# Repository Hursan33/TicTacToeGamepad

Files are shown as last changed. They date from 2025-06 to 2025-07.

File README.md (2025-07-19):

# TicTacToeGamepad

## TBD 
Test new version of code, assemble the integrated arduino version, upload edited case

## 1 Introduction
This project is an implementation of a Tic Tac Toe game using both hardware and software. The
purpose of the project was to practice working with an 8-bit mcu on register level, but I worked on it more and created a standalone version.
## 2 Materials and technologies
* MCU (I used Avr curiosity nano for school and an Arduino pro micro for standalone)  
* 9x Keyboard switches  
* 9x SK6812MINI-E LEDs  
* 3x 100uF capacitors  
* 1x 330r resistor  
  
The game itself is played on a 3x3 playing field made from keyboard switches, which are soldered onto
a PCB I designed. The PCB sits in a 3D printed case.

## 2 Functions
The game uses addressable LEDs to show the board state. Each player has their own color, which is
shown on the fields the player has occupied. After the game is over, whether it was a draw or a player
won, there is an animation and 5 second delay, after which the game restarts. The first player to act
is decided by which player won the last game, or which player went last. There are 2 possible game
modes:  

* Classic  
* 3-mark rule  

Both game modes can be played in single player, which replaces the second player with a bot.
### 2.1 Classic
This game mode uses the classic rules of a 3x3 tic tac toe game. The player wins by putting 3 marks
in a row, column or diagonal. After the board is filled and no player has won, the game is declared as
a draw.
1
### 2.2 3-mark rule
Here each player only gets 3 marks. After that they must move their oldest mark to a new position.
In this game mode there is no draw, a player must win to end the game. The moving mark is shown
by being dimmer than the rest.
### 2.3 Bot
The bot uses a simple algorithm to decide which space it wants to occupy.
1. Checks if a win is possible, then it places the mark there.  
2. Checks if the player can win, then it blocks the player.  
3. If the center is free, it puts the mark there.  
4. Checks every corner in a random order and occupies it if possible.  
5. Checks every side field in a random order and occupies it if possible.

In the 3-mark rule, when checking if the player can win, it also remembers which mark the player is
moving. This ensures that the bot blocks the correct field.
### 3.4 Ending animation
After the game ends, either by a player winning or a draw, there is an animation played. The animation
lights up the LEDs in a “2” shape with the color of the winning player, or in the case of a draw with
the “draw” color.
## 3 Costumizations
There are a few customizations in the game. First, the game mode and if the bot is active can be
set. The colors of each player and draw are also customizable, using RGB format. The dimness of the
moving mark is also possible to change.
To change these settings these macros can be modified in the “config.h” file:

* GAME_MODE – 1 (3-mark rule) or 0 (Classic).  
* BOT – 1 (Bot is turned on) or 0 (Bot is off).  
* PLAYER_N_COLOR and DRAW_COLOR – has this syntax (Color) R, G, B, you replace the R, G, B
with the corresponding colors of the value. Player colors and draw color all have to be different
otherwise an error occurs.  
* DIM_DIV – the amount by which the values of the color are divided, e.g. DIM_DIV 16 makes the
LEDs be 1
16 of their brightness.  

If there were changes to any of the settings the game can be simply re-flashed onto the mcu by using
the Makefile in the project folder.
### 3.1 Error
If an error occurs, the board starts blinking red. In case this happens check your color values, because
some of them have the same values.
## Schematic and PCB


The gerber files for the PCB are present in the repository.
## PINOUT


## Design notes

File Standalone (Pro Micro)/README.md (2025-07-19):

# Standalone arduino pro micro version
This is a reworked version of the TicTacToe gamepad. It is has a battery and no need to be plugged into a computer.
## 1 Software
Sadly, I was unable to get the timing right for the LEDs. In the end, I decided to use Arduino code (instead of bare metal) and used the Neopixel library to control the LEDs.
## 2 Components
This variant of the projects uses additional components. 
* 3 x sliding switches like [this](https://www.aliexpress.com/item/1005005877582064.html?spm=a2g0o.order_list.order_list_main.116.5a0a1802KlUbMT) one
* 1 x charging circuit like [this](https://www.aliexpress.com/item/1005006734963929.html?spm=a2g0o.order_list.order_list_main.22.2a7718028qB14W)
* 1 x small lithium battery, I used a 180mAh battery because it was small and I had it already on hand, but a bigger battery wouldn't hurt.
## 3 Images and building
a3
a2
a1
2 of the 3 switches are connected to pins A0 and A2, the position of these switches at startup controls whether the Bot or 3-mark rule functionalities are turned on, thus there is no need to edit the code. The last switch is the power switch and completes the circuit between the MCU and the charging circuit. I repurposed an old micro usb connecter between the MCU and charging circuit but you can hardwire it.
The pin connections can be found in the code [here](https://github.com/Hursan33/TicTacToeGamepad/blob/main/Standalone%20(Pro%20Micro)/firmware.ino).

a4
a5
a6

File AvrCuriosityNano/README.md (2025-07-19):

# Avr Curiosity Nano version
This version of the software is written in C, compiled using avrgcc and flashed with avrdude. I wrote the driver for
the LEDs, which are sensitive to timing, so I decided to use `nop` instructions. They are used to create delay, which is more accurate than using delay functions from
`<util/delay.h>`. For the number of cycles, I used the LED datasheet as a reference. 
## Status
This version of the project was an assignment on a school course and will *NOT* be updated anymore.
## Connection
In this version the MCU was connected via the 9 pins present on the PCB, 
but it can be made completely stand-alone.
## Images



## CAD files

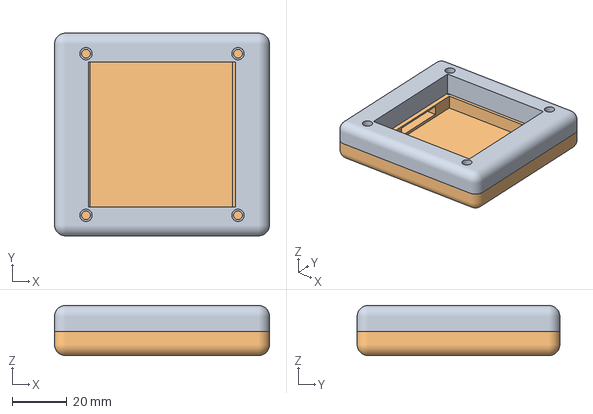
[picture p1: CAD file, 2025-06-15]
AvrCuriosityNano/game_pad_case.3mf
78.5 x 74.0 x 18.3 mm
TopCase

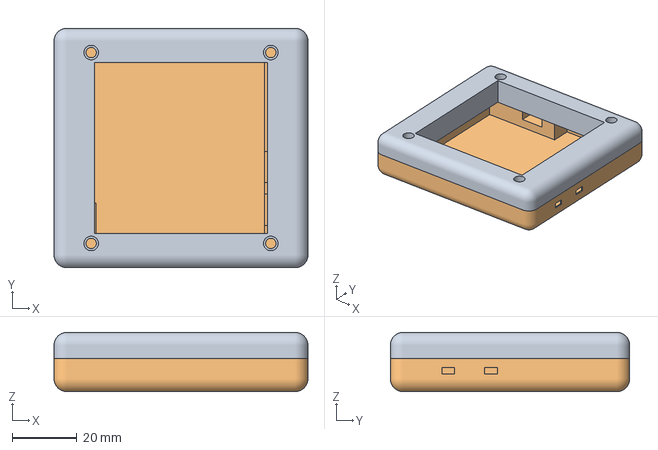
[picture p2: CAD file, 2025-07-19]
Standalone (Pro Micro)/Case.3mf
78.5 x 74.0 x 18.3 mm
TopCase

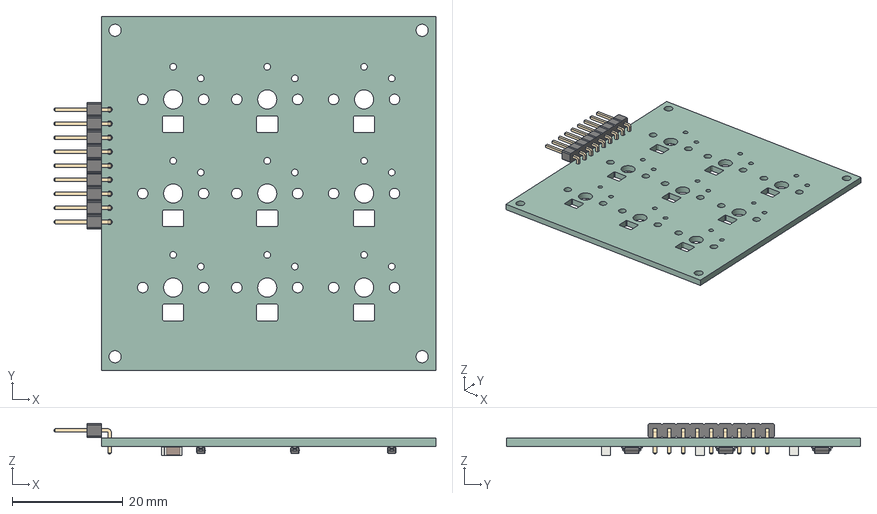
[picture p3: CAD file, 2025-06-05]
TicTacToe-KiCad/TicTacToe - pb171.step
69.0 x 64.0 x 5.82 mm
PinHeader_1x09_P2.54mm_Horizontal
D_SOD-123 x 9
C_1206_3216Metric x 3
TicTacToe - pb171_PCB

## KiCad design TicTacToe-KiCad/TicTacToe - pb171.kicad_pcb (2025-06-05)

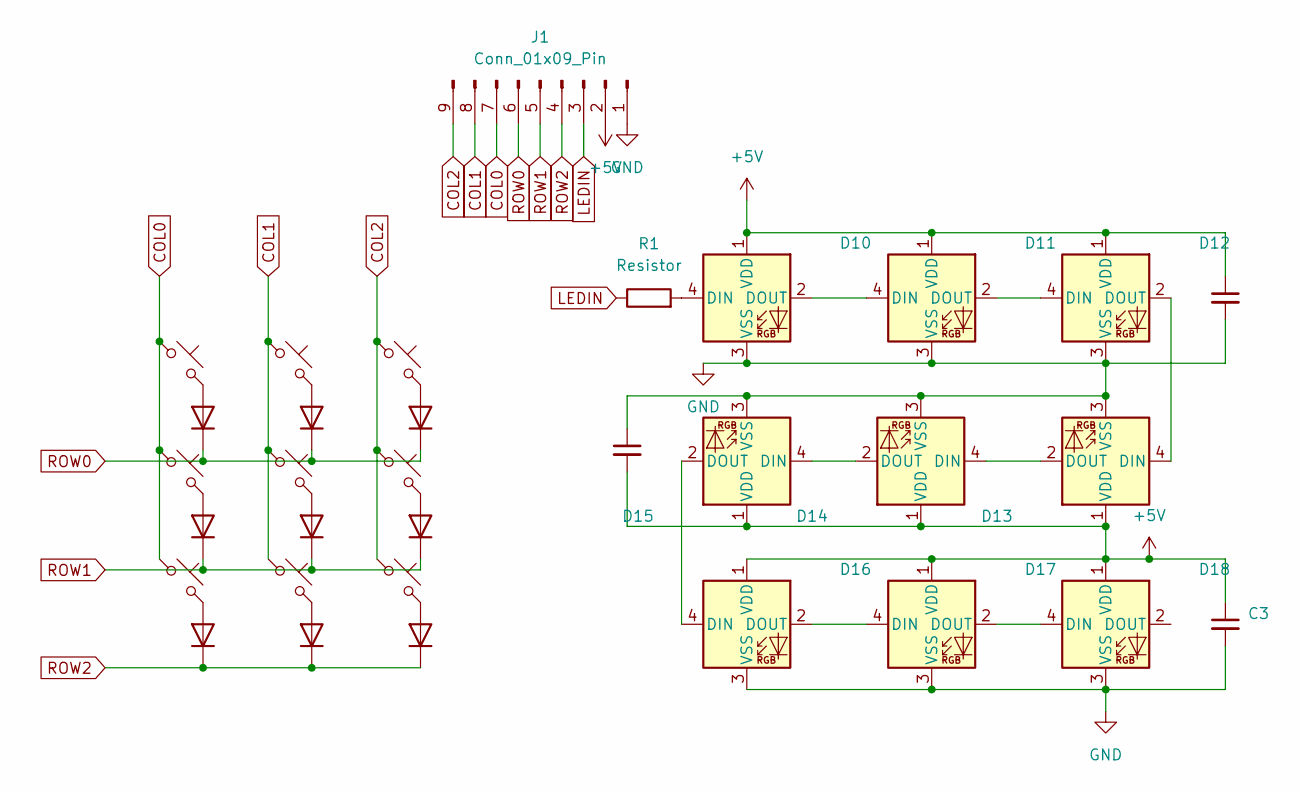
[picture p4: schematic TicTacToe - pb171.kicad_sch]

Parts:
C1, C2, C3: C_Small; C_1206_3216Metric
D1, D2, D3, D4, D5, D6, D7, D8, D9: D; D_SOD-123
D10, D11, D12, D13, D14, D15, D16, D17, D18: LED_WS2812B; SK6812-MINI-E
J1: Conn_01x09_Pin; PinHeader_1x09_P2.54mm_Horizontal
R1: Resistor; Resistor_1206
S1, S2, S3, S4, S5, S6, S7, S8, S9: Keyswitch; Choc_V1_1.00u

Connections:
+5V: C1.1, C2.2, C3.1, D10.1 (VDD), D11.1 (VDD), D12.1 (VDD), D13.1 (VDD), D14.1 (VDD), D15.1 (VDD), D16.1 (VDD), D17.1 (VDD), D18.1 (VDD), J1.2
COL0: J1.7, S1.1, S4.1, S7.1
COL1: J1.8, S2.1, S5.1, S8.1
COL2: J1.9, S3.1, S6.1, S9.1
GND: C1.2, C2.1, C3.2, D10.3 (VSS), D11.3 (VSS), D12.3 (VSS), D13.3 (VSS), D14.3 (VSS), D15.3 (VSS), D16.3 (VSS), D17.3 (VSS), D18.3 (VSS), J1.1
LEDIN: J1.3, R1.1
unnamed: D1.2 (A), S1.2
unnamed: D2.2 (A), S2.2
unnamed: D3.2 (A), S3.2
unnamed: D4.2 (A), S4.2
unnamed: D5.2 (A), S5.2
unnamed: D6.2 (A), S6.2
unnamed: D7.2 (A), S7.2
unnamed: D8.2 (A), S8.2
unnamed: D9.2 (A), S9.2
unnamed: D10.4 (DIN), R1.2
unnamed: D10.2 (DOUT), D11.4 (DIN)
unnamed: D11.2 (DOUT), D12.4 (DIN)
unnamed: D12.2 (DOUT), D13.4 (DIN)
unnamed: D13.2 (DOUT), D14.4 (DIN)
unnamed: D14.2 (DOUT), D15.4 (DIN)
unnamed: D15.2 (DOUT), D16.4 (DIN)
unnamed: D16.2 (DOUT), D17.4 (DIN)
unnamed: D17.2 (DOUT), D18.4 (DIN)
ROW0: D1.1 (K), D2.1 (K), D3.1 (K), J1.6
ROW1: D4.1 (K), D5.1 (K), D6.1 (K), J1.5
ROW2: D7.1 (K), D8.1 (K), D9.1 (K), J1.4

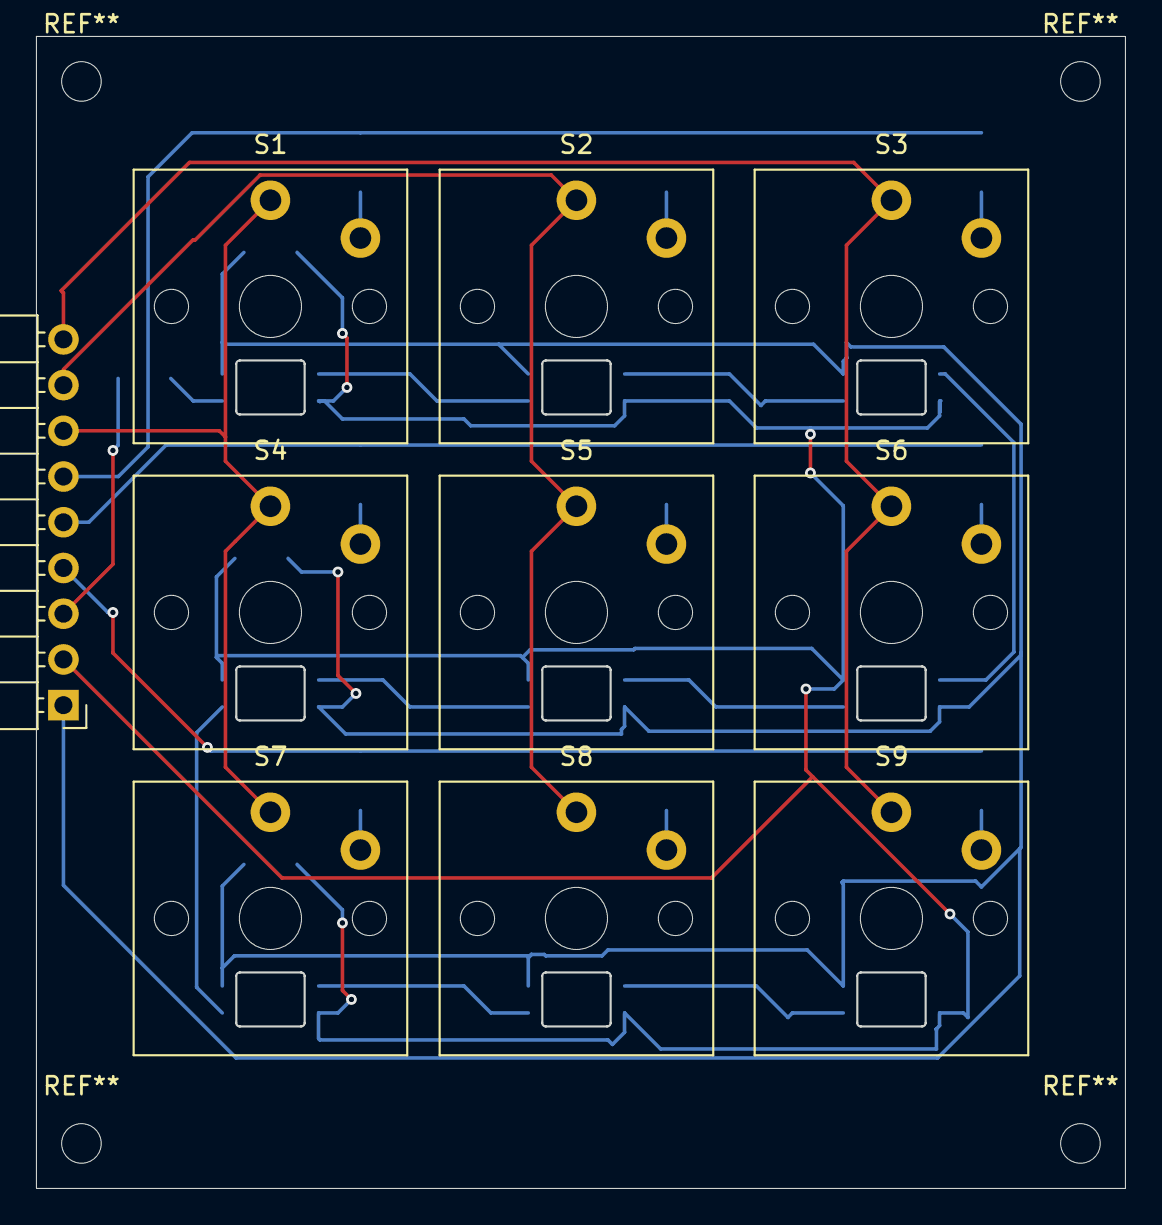
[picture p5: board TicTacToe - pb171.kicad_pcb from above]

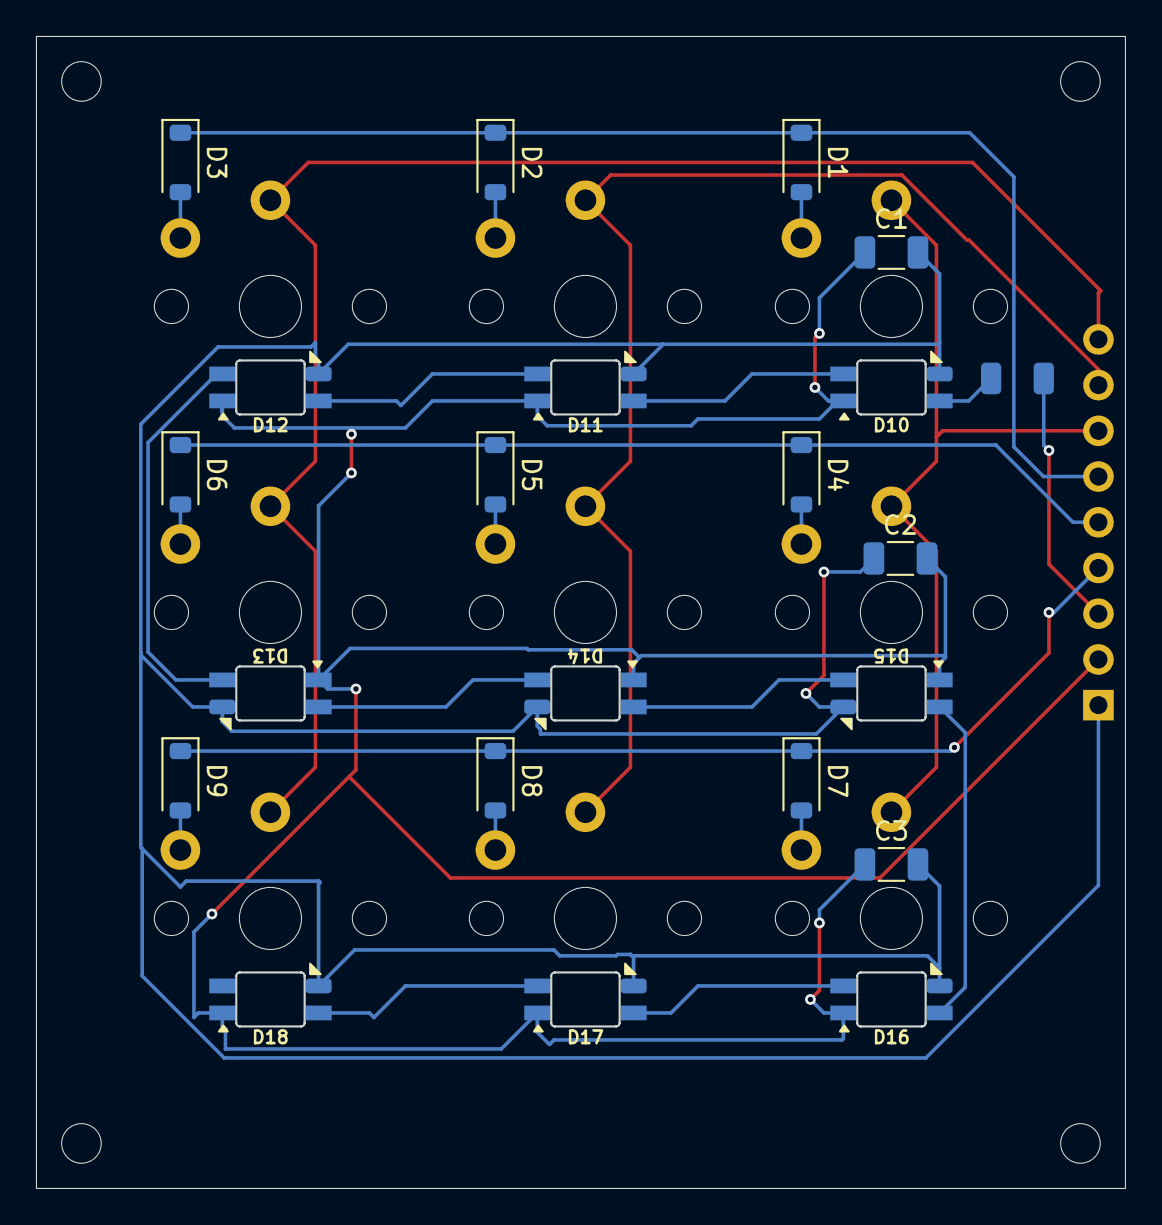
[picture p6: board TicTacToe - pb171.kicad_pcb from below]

Board: 2 copper layers, 60.5 x 64.0 mm, 32 parts (22 on the bottom side), 27 nets.

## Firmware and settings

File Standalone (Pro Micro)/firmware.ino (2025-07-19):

#include <Adafruit_NeoPixel.h> // Include the NeoPixel library

#define LED_PIN    4    // Digital pin connected to the NeoPixel data input
#define NUM_LEDS   9    // Number of NeoPixels in your 3x3 grid
#define ANIM_SPEED 200

Adafruit_NeoPixel pixels(NUM_LEDS, LED_PIN, NEO_GRB + NEO_KHZ800);

uint8_t GAME_MODE;
uint8_t BOT;
uint8_t PLAYER_1_COLOR[3] = {255, 0, 247};
uint8_t PLAYER_2_COLOR[3] = {0, 255, 8};
uint8_t DRAW_COLOR[3] = {255, 0, 0};
#define DIM_DIV 16 //Sets the brightness of the dim space (only GAMEMODE 1),
                   //Decides by what number will the values of color be dived by

const int rowPins[] = {8, 7, 6}; // Row 0 (top) -> A3, Row 1 (middle) -> A2, Row 2 (bottom) -> A1

const int colPins[] = {14, 16, 10}; // Col 0 (left) -> Pin 15, Col 1 (middle) -> Pin 16, Col 2 (right) -> Pin 14

int keypadToNeoPixelIndex[3][3] = {
  {0, 1, 2}, // If Key '1' -> LED 0, '2' -> LED 1, '3' -> LED 2
  {5, 4, 3}, // If Key '4' -> LED 3, '5' -> LED 4, '6' -> LED 5
  {6, 7, 8}  // If Key '7' -> LED 6, '8' -> LED 7, '9' -> LED 8
};

uint8_t board[3][3] = {{0}};
    
uint8_t player1_moves[3][2] = {{255}};
uint8_t player2_moves[3][2] = {{255}};
uint8_t p1_count = 0;
uint8_t p2_count = 0;

uint8_t turnCounter = 0;
uint8_t row = 0;
uint8_t col = 0;
uint8_t player;
uint8_t banned_c = -1;
uint8_t banned_r = -1;


void setup() {
  pinMode(A2, INPUT_PULLUP);
  pinMode(A0, INPUT_PULLUP);
  
  
  GAME_MODE = digitalRead(A0) == LOW;  //OR put 0, for traditional tic-tac-toe
  BOT = digitalRead(A2) == LOW;
  
  Serial.begin(9600);
  
  // Initialize NeoPixel strip
  pixels.begin();         // Initialize the NeoPixel library
  pixels.clear();         // Turn off all NeoPixels initially
  pixels.show();          // Send the updated pixel colors to the hardware.

  // Set row pins as outputs and ensure they are all LOW initially (inactive)
  for (int i = 0; i < 3; i++) {
    pinMode(rowPins[i], OUTPUT);
    digitalWrite(rowPins[i], HIGH); // All rows are inactive (LOW) by default
  }

  // Set column pins as inputs and enable internal pull-up resistors
  for (int i = 0; i < 3; i++) {
    pinMode(colPins[i], INPUT_PULLUP);
  }
}

void loop() {
  Serial.println("BOT AND GAMEMODE");
  Serial.print(BOT);
  Serial.print(" ");
  Serial.println(GAME_MODE);
  printBoard(board);
  player = turnCounter % 2 == 0 ? 1 : 2;
  uint8_t (*moves)[2] = player == 1 ? player1_moves : player2_moves;
  uint8_t *move_count = player == 1 ? &p1_count : &p2_count;
  uint8_t *color = player == 1 ? PLAYER_1_COLOR : PLAYER_2_COLOR;

  if (GAME_MODE) {
      if (*move_count == 3) {
          pixels.setPixelColor(keypadToNeoPixelIndex[moves[0][0]][moves[0][1]], pixels.Color(color[0] / DIM_DIV, color[1] / DIM_DIV, color[2] / DIM_DIV));
          pixels.show();
      }
  }
  
  
  while (!scanKey(&row, &col)) {}
  if (board[row][col] != 0) {
      return;
  }

  if (GAME_MODE) {
      remove_old(board, moves, move_count);
      moves[*move_count - 1][0] = row;
      moves[*move_count - 1][1] = col;
  }
  
  board[row][col] = player;
  pixels.setPixelColor(keypadToNeoPixelIndex[row][col], pixels.Color(color[0], color[1], color[2]));
  pixels.show();
  
  check_end(board, player, &p1_count, &p2_count, &banned_c, &banned_r);
  
  turnCounter++;

  if (!BOT) {
      return;
  }

  delay(500);
  player = 2;
  color = PLAYER_2_COLOR;
  moves = player2_moves;
  move_count = &p2_count;

  int bot_c, bot_r;
  if (GAME_MODE) {
      if (*move_count == 3) {
          banned_c = moves[0][1];
          banned_r = moves[0][0];

          pixels.setPixelColor(keypadToNeoPixelIndex[moves[0][0]][moves[0][1]], pixels.Color(color[0] / DIM_DIV, color[1] / DIM_DIV, color[2] / DIM_DIV));
          pixels.show();
          _delay_ms(1000);
      }
      remove_old(board, moves, move_count);
  }

  bot_move(board, &bot_r, &bot_c, banned_r, banned_c, p1_count, player1_moves[0]);
  Serial.print("Bot moved to ");
  Serial.print(bot_r);
  Serial.print(" ");
  Serial.println(bot_c);
  if (GAME_MODE) {
      moves[*move_count - 1][0] = bot_r;
      moves[*move_count - 1][1] = bot_c;
  }

  pixels.setPixelColor(keypadToNeoPixelIndex[bot_r][bot_c], pixels.Color(color[0], color[1], color[2]));
  pixels.show();

  check_end(board, player, &p1_count, &p2_count, &banned_c, &banned_r);

  turnCounter++;
}

bool prev_states[3][3] = {{true}};

bool gameEnded(uint8_t board[3][3], int currPlayer, bool botCheck) {
    for (int i = 0; i < 3; i++) {
        if (board[i][0] == board[i][1] && board[i][1] == board[i][2] && board[i][0] == currPlayer){
            int winners[3][2] = {{i, 0}, {i, 1}, {i, 2}};
            if (!botCheck) {
              blinkWinner(winners, currPlayer == 1 ? PLAYER_1_COLOR : PLAYER_2_COLOR);
            }
            return true;
        }
    }
    
    for (int i = 0; i < 3; i++) {
        if (board[0][i] == board[1][i] && board[1][i] == board[2][i] && board[0][i] == currPlayer){
            int winners[3][2] = {{0, i}, {1, i}, {2, i}};
            if (!botCheck) {
              blinkWinner(winners, currPlayer == 1 ? PLAYER_1_COLOR : PLAYER_2_COLOR);
            }
            return true;
        }
    }
    
    if (board[0][0] == board[1][1] && board[1][1] == board[2][2] && board[0][0] == currPlayer) {
        int winners[3][2] = {{0, 0}, {1, 1}, {2, 2}};
        if (!botCheck) {
          blinkWinner(winners, currPlayer == 1 ? PLAYER_1_COLOR : PLAYER_2_COLOR);
        }
        return true;
    }
    
    if (board[2][0] == board[1][1] && board[1][1] == board[0][2] && board[2][0] == currPlayer) {
        int winners[3][2] = {{2, 0}, {1, 1}, {0, 2}};
        if (!botCheck) {
          blinkWinner(winners, currPlayer == 1 ? PLAYER_1_COLOR : PLAYER_2_COLOR);
        }
        return true;
    }
    
    return false;
}

bool scanKey(uint8_t* row, uint8_t* col) {
    bool keyPressed = false;
    for (int r = 0; r < 3; r++) {
        digitalWrite(rowPins[r], LOW);
        _delay_ms(5);

        for(int c = 0; c < 3; c++) {
            bool pressed = !(digitalRead(colPins[c]));
                
            if (pressed && !prev_states[r][c]) {
                *col = c;
                *row = r;
                Serial.print("found ");
                Serial.print(c);
                Serial.print(" ");
                Serial.println(r);
                keyPressed = true;
            }
            
            prev_states[r][c] = pressed;
        }

        digitalWrite(rowPins[r], HIGH);
        _delay_ms(20);
    }
    
    return keyPressed;
}

bool drawCheck(uint8_t board[3][3]) {
    for (int i = 0; i < 3; i++) {
        for (int j = 0; j < 3; j++) {
            if (board[i][j] == 0) {
                return false;
            }
        }
    }
    
    return true;
}

void remove_old(uint8_t board[3][3], uint8_t moves[3][2], uint8_t *move_count) {
    if (*move_count == 3) {
        uint8_t *move = moves[0];

        board[move[0]][move[1]] = 0;

        uint8_t led = move[0] * 3 + move[1];
        if (move[0] == 1) {
            led = 3 + (2 - move[1]);
        }
        pixels.setPixelColor(keypadToNeoPixelIndex[move[0]][move[1]], pixels.Color(0, 0, 0));

        for (int i = 0; i < 2; i++) {
            moves[i][0] = moves[i + 1][0];
            moves[i][1] = moves[i + 1][1];
        }
    } else {
        (*move_count)++;
    }

    
}

bool is_empty(uint8_t board[3][3], int row, int col) {
    return board[row][col] == 0;
}

void randomize(int indices[4]) {
    for (int i = 3; i >= 0; --i){
        //generate a random number [0, n-1]
        int j = rand() % 4;

        //swap the last element with element at random index
        int temp = indices[i];
        indices[i] = indices[j];
        indices[j] = temp;
    }
}

void bot_move(uint8_t board[3][3], int *row, int *col, int b_r, int b_c, int moves_count, uint8_t move[2]) {
    for (int i = 0; i < 3; i++) {
        for (int j = 0; j < 3; j++) {
            if (b_c != -1 && b_r == i && b_c == j) {
                continue;
            }
            if (is_empty(board, i, j)) {

                board[i][j] = 2;
                if (gameEnded(board, 2, true)) {
                    //ZAPISE A VYHRA
                    *col = j;
                    *row = i;
                    return;
                }
                board[i][j] = 0;

            }
        }
    }

    for (int i = 0; i < 3; i++) {
        for (int j = 0; j < 3; j++) {
            if (b_c != -1 && b_r == i && b_c == j) {
                continue;
            }
            if (is_empty(board, i, j)) {
                board[i][j] = 1;
                if (moves_count == 3) {
                    board[move[0]][move[1]] = 0;
                }
                if (gameEnded(board, 1, true)) {
                    //ZAPISE A BLOKUJE
                    board[i][j] = 2;
                    *col = j;
                    *row = i;
                    return;
                }
                board[i][j] = 0;
                if (moves_count == 3) {
                    board[move[0]][move[1]] = 1;
                }
            }
        }
    }

    if (!(b_c != -1 && b_c == 1 && b_r == 1) && is_empty(board, 1, 1)) {
        *col = 1;
        *row = 1;
        board[1][1] = 2;
        return;
    }

    int indices[4] = {0, 1, 2, 3};
    randomize(indices);

    int corners[4][2] = { {0,0}, {0,2}, {2,0}, {2,2} };
    for (int i = 0; i < 4; i++) {
        int c = corners[indices[i]][1];
        int r = corners[indices[i]][0];
        if (b_c != -1 && b_c == c && b_r == r) {
            continue;
        }
        if (is_empty(board, r, c)) {
            Serial.print(c);
            Serial.println(r);
            board[r][c] = 2;
            *col = c;
            *row = r;
            return;
        }
    }

    randomize(indices);

    int sides[4][2] = { {0,1}, {1,0}, {2,1}, {1,2} };
    for (int i = 0; i < 4; i++) {
        int c = sides[indices[i]][1];
        int r = sides[indices[i]][0];
        if (b_c != -1 && b_c == c && b_r == r) {
            continue;
        }
        if (is_empty(board, r, c)) {
            board[r][c] = 2;
            *col = c;
            *row = r;
            return;
        }
    }
}

void check_end(uint8_t board[3][3], int player, uint8_t *p1_count, 
    uint8_t *p2_count, uint8_t *banned_c, uint8_t *banned_r) {
    bool game_ended = gameEnded(board, player, false);
    if (game_ended || drawCheck(board)) {
        ending_animation(game_ended ? (player == 1 ? PLAYER_1_COLOR : PLAYER_2_COLOR) : DRAW_COLOR);
        
        for (int i = 0; i < 3; i++) {
            for (int j = 0; j < 3; j++) {
                board[i][j] = 0;
            }
        }
        
        *p1_count = 0;
        *p2_count = 0;
        *banned_c = -1;
        *banned_r = -1;
    }
}

void ending_animation(uint8_t* rgb) {

    delay(700);
    pixels.clear();
    pixels.show();
    delay(ANIM_SPEED);
    for (int i = 0; i < 9; i++) {
        pixels.setPixelColor(i, pixels.Color(rgb[0], rgb[1], rgb[2]));
        pixels.show();
        delay(ANIM_SPEED);
    }

    for (int i = 0; i < 3; i++) {
        delay(400);
        pixels.clear();
        pixels.show();
        delay(400);
        for (int j = 0; j < 9; j++) {
            pixels.setPixelColor(j, pixels.Color(rgb[0], rgb[1], rgb[2]));
        }
        pixels.show();
    }

    delay(2500);
    pixels.clear();
    pixels.show();
}

void blinkWinner(int winners[3][2], uint8_t* rgb) {
  for (int j = 0; j < 3; j++) { 
    delay(ANIM_SPEED * 2);
    for (int i = 0; i < 3; i++) {
      int index = keypadToNeoPixelIndex[winners[i][0]][winners[i][1]];
      Serial.print(winners[i][0]);
      Serial.println(winners[i][1]);
      pixels.setPixelColor(index, pixels.Color(0,0,0));
    }
    pixels.show();
    delay(ANIM_SPEED * 2);
    for (int i = 0; i < 3; i++) {
      int index = keypadToNeoPixelIndex[winners[i][0]][winners[i][1]];
      pixels.setPixelColor(index, pixels.Color(rgb[0],rgb[1],rgb[2]));
    }
    pixels.show();
  }
}

//
//bool check_color(Color color1, Color color2) {
//    return color1.rgb[0] == color2.rgb[0] &&
//            color1.rgb[1] == color2.rgb[1] &&
//            color1.rgb[2] == color2.rgb[2];
//}

void error_anim() {
    while (1) {
        for (int j = 0; j < 9; j++) {
            pixels.setPixelColor(j, pixels.Color(255, 0, 0));
        }
        pixels.show();
        delay(400);
        pixels.clear();
        pixels.show();
        delay(400);
    }
}

void printBoard(uint8_t board[3][3]) {
  Serial.println("\nCurrent Board:");
  Serial.println("-------------");
  
  for (int row = 0; row < 3; row++) {
    Serial.print("| ");
    for (int col = 0; col < 3; col++) {
      switch (board[row][col]) {
        case 1: Serial.print("X"); break;
        case 2: Serial.print("O"); break;
        default: Serial.print(" "); break;
      }
      Serial.print(" | ");
    }
    Serial.println("\n-------------");
  }
}

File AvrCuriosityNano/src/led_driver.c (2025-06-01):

/*
 * File:   led_driver.c
 * Author: hursa
 *
 * Created on May 12, 2025, 11:40 PM
 */


#include <avr/io.h>
#define F_CPU 20000000
#include <util/delay.h>
#include <avr/interrupt.h>
#include <stdint.h>
#include "led_driver.h"

#define ANIM_SPEED 200

// Send one byte to WS2812
static void send_byte(uint8_t byte) {
    for (uint8_t i = 0; i < 8; i++) {
        if (byte & (1 << (7 - i))) {
            // Send '1' bit
            PORTD.OUTSET = PIN0_bm;       // HIGH
            __builtin_avr_delay_cycles(13); // ~0.8�s
            PORTD.OUTCLR = PIN0_bm;       // LOW
            __builtin_avr_delay_cycles(6);  // ~0.45�s
        } else {
            // Send '0' bit
            PORTD.OUTSET = PIN0_bm;       // HIGH
            __builtin_avr_delay_cycles(4);  // ~0.35�s
            PORTD.OUTCLR = PIN0_bm;       // LOW
            __builtin_avr_delay_cycles(14); // ~0.9�s
        }
    }
}

void send_rgb(uint8_t *rgb_data, uint16_t len) {
    cli();
    for (uint16_t i = 0; i < len; i++) {
        send_byte(rgb_data[i]);
    }

    sei();
}

void flush_strip(Strip strip, uint8_t led_count) {
    for (int i = 0; i < led_count; i++) {
        send_rgb(strip.led[i].rgb, 3);
    }
    
    _delay_us(50);
}

void set_color(Strip *strip, Color color, int col, int row) {
    uint8_t led = col * 3 + row;
    if (col == 1) {
        led = 3 + (2 - row);
    }
    strip->led[led].rgb[1] = color.rgb[0];
    strip->led[led].rgb[0] = color.rgb[1];
    strip->led[led].rgb[2] = color.rgb[2];
}

void set_color_true_pos(Strip *strip, int led_count, Color color) {
    strip->led[led_count].rgb[1] = color.rgb[0];
    strip->led[led_count].rgb[0] = color.rgb[1];
    strip->led[led_count].rgb[2] = color.rgb[2];
}

void clear_strip(Strip *strip, uint8_t led_count) {
    for (int i = 0; i < led_count; i++) {
        strip->led[i].rgb[0] = 0;
        strip->led[i].rgb[1] = 0;
        strip->led[i].rgb[2] = 0;
    }
}

void ending_animation(Strip *s, Color color) {

    _delay_ms(700);
    clear_strip(s, 9);
    flush_strip(*s, 9);
    _delay_ms(ANIM_SPEED);
    for (int i = 0; i < 9; i++) {
        set_color_true_pos(s, i, color);
        flush_strip(*s, 9);
        _delay_ms(ANIM_SPEED);
    }

    for (int i = 0; i < 3; i++) {
        _delay_ms(400);
        clear_strip(s, 9);
        flush_strip(*s, 9);
        _delay_ms(400);
        for (int j = 0; j < 9; j++) {
            set_color_true_pos(s, j, color);
        }
        flush_strip(*s, 9);
    }

    _delay_ms(5000);
    clear_strip(s, 9);
    flush_strip(*s, 9);
}

Color get_dim(Color color, int DIM_DIV) {
    return (Color) {{(int) (color.rgb[0] / DIM_DIV), (int) (color.rgb[1] / DIM_DIV), (int) (color.rgb[2] / DIM_DIV)}};
}

bool check_color(Color color1, Color color2) {
    return color1.rgb[0] == color2.rgb[0] &&
            color1.rgb[1] == color2.rgb[1] &&
            color1.rgb[2] == color2.rgb[2];
}

void error_anim(Strip *s) {
    while (1) {
        for (int j = 0; j < 9; j++) {
            set_color_true_pos(s, j, (Color) {{255, 0, 0}});
        }
        flush_strip(*s, 9);
        _delay_ms(400);
        clear_strip(s, 9);
        flush_strip(*s, 9);
        _delay_ms(400);
    }
}

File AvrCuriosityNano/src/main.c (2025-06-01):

#include <avr/io.h>
#include <stdbool.h>
#define F_CPU 20000000
#include <util/delay.h>
#include <assert.h>

#include "led_driver.h"
#include "tic-tac-toe.h"
#include "config.h"

int main(void) {
    
    cli();
    
    CPU_CCP = CCP_IOREG_gc;
    CLKCTRL.MCLKCTRLB = 0x00;

    sei();
    setupIO();
    uint8_t board[3][3] = {{0}};
    
    uint8_t player1_moves[3][2] = {{255}};
    uint8_t player2_moves[3][2] = {{255}};
    uint8_t p1_count = 0;
    uint8_t p2_count = 0;
    
    uint8_t turnCounter = 0;
    uint8_t row = 0;
    uint8_t col = 0;
    uint8_t player;
    PORTD.DIR = 0xff;
    uint8_t banned_c = -1;
    uint8_t banned_r = -1;
    
    Strip s = {0};
    flush_strip(s, 9);

    if (check_color(PLAYER_1_COLOR, PLAYER_2_COLOR) || 
        check_color(PLAYER_1_COLOR, DRAW_COLOR) ||
        check_color(PLAYER_2_COLOR, DRAW_COLOR)) {
            error_anim(&s);
    }
    
    while (1) {
        player = turnCounter % 2 == 0 ? 1 : 2;
        uint8_t (*moves)[2] = player == 1 ? player1_moves : player2_moves;
        uint8_t *move_count = player == 1 ? &p1_count : &p2_count;
        Color color = player == 1 ? PLAYER_1_COLOR : PLAYER_2_COLOR;

        if (GAME_MODE) {
            if (*move_count == 3) {
                set_color(&s, get_dim(color, DIM_DIV), moves[0][0], moves[0][1]);
                flush_strip(s, 9);
            }
        }
        
        
        while (!scanKey(&col, &row)) {}
        if (board[col][row] != 0) {
            continue;
        }

        if (GAME_MODE) {
            remove_old(board, moves, move_count, &s);
            moves[*move_count - 1][0] = col;
            moves[*move_count - 1][1] = row;
        }
        
        board[col][row] = player;
        set_color(&s, color, col, row);
        flush_strip(s, 9);
        
        check_end(board, &s, player, &p1_count, &p2_count, &banned_c, &banned_r);
        
        turnCounter++;

        if (!BOT) {
            continue;
        }

        _delay_ms(500);
        player = 2;
        color = PLAYER_2_COLOR;
        moves = player2_moves;
        move_count = &p2_count;

        int bot_c, bot_r;
        if (GAME_MODE) {
            if (*move_count == 3) {
                banned_c = moves[0][0];
                banned_r = moves[0][1];

                set_color(&s, get_dim(color, DIM_DIV), moves[0][0], moves[0][1]);
                flush_strip(s, 9);
                _delay_ms(1000);
            }
            remove_old(board, moves, move_count, &s);
        }

        bot_move(board, &bot_c, &bot_r, banned_c, banned_r, p1_count, player1_moves[0]);
        if (GAME_MODE) {
            moves[*move_count - 1][0] = bot_c;
            moves[*move_count - 1][1] = bot_r;
        }

        set_color(&s, color, bot_c, bot_r);
        flush_strip(s, 9);

        check_end(board, &s, player, &p1_count, &p2_count, &banned_c, &banned_r);

        turnCounter++;
    }
}

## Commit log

2025-06-01 Feat: uploaded source code and README for AVR curiosity nano board
2025-06-02 Added arduino uno version of code | compiles, but have not tested on hardware | edited formattin
2025-06-05 Updated few lines in arduino version
2025-06-05 Added gerber file for PCB
2025-06-05 Added KiCad project
    [TicTacToe - pb171.kicad_pcb, TicTacToe - pb171.kicad_sch, TicTacToe - pb171.step]
2025-06-15 Updated formatting of readme and added model for AvrCuriosity version
    [game_pad_case.step]
2025-06-15 Exchanged step file for stl
    [game_pad_case.step]
2025-06-15 Forgot to push file
    [game_pad_case.stl]
2025-06-15 Once again switched formats, so it keeps multiple parts
    [game_pad_case.3mf, game_pad_case.stl]
2025-07-19 Added 3d model for keypad
    [Case.3mf]
